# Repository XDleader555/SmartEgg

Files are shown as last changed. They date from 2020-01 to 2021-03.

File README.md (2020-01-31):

# SmartEgg
Data collection firmware for an ESP32 based egg drop.

## Usage
See the [wiki page](https://github.com/XDleader555/SmartEgg/wiki) for help operating the egg.

## Specifications
MCU: [Adafruit HUZZAH32](https://www.adafruit.com/product/3405)

Weight: 76.25 grams

Material: PET-G

Width: 53.10 mm (2.09 in)

Height: 70.53 mm (2.78 in)

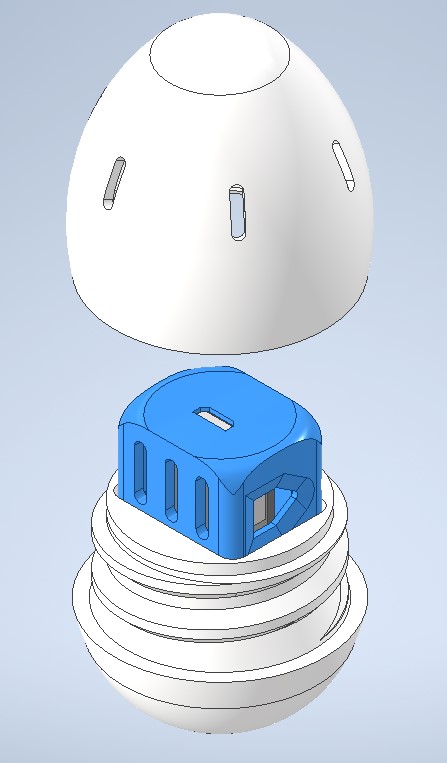
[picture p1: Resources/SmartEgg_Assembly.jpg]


## Prerequisites
This project needs to be compiled using the latest esp-idf which supports the ardino-esp32 core.
You'll also need esptool. win32 mkspiffs is included.

### esptool
Make sure that python is added to your path and run
```
pip install esptool
```

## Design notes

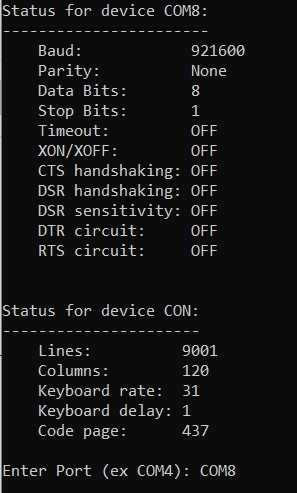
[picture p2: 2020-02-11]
Resources/COM Port.jpg

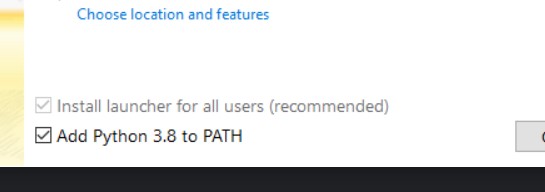
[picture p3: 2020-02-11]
Resources/Python Path.jpg

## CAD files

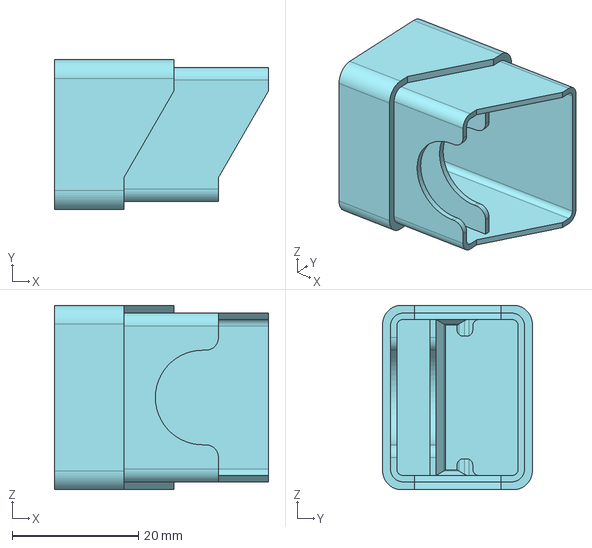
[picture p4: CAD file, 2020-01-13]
CAD/STEP/SmartEgg Housing Main.stp
33.9 x 23.8 x 29.2 mm

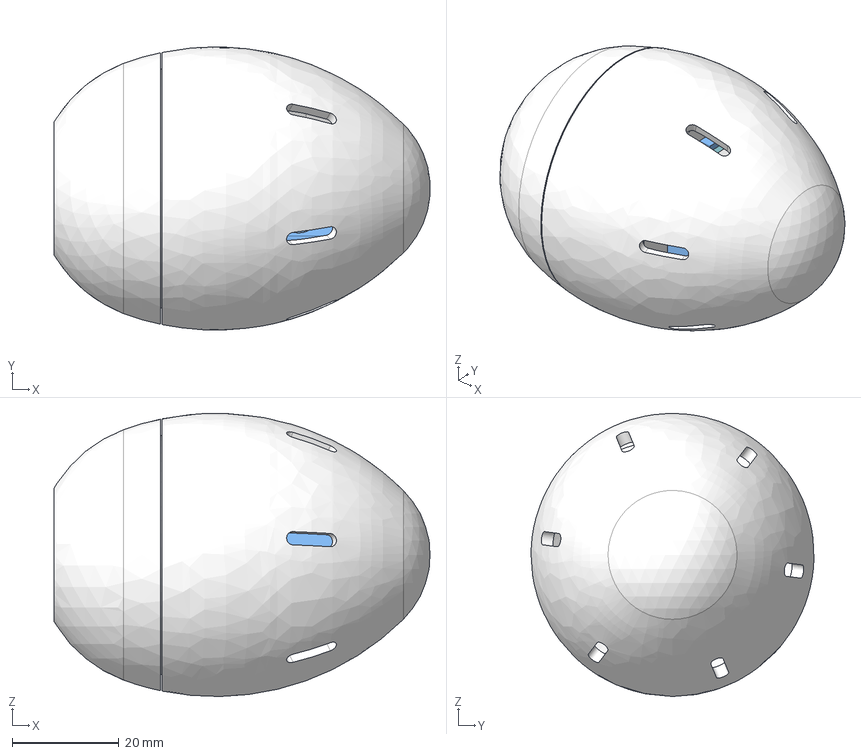
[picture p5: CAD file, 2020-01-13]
CAD/STEP/SmartEgg.stp
70.5 x 53.0 x 53.0 mm
ESP32 Feather
SmartEgg Housing Main
SmartEgg Housing Cap
SmartEgg Shell Top
SmartEgg Shell

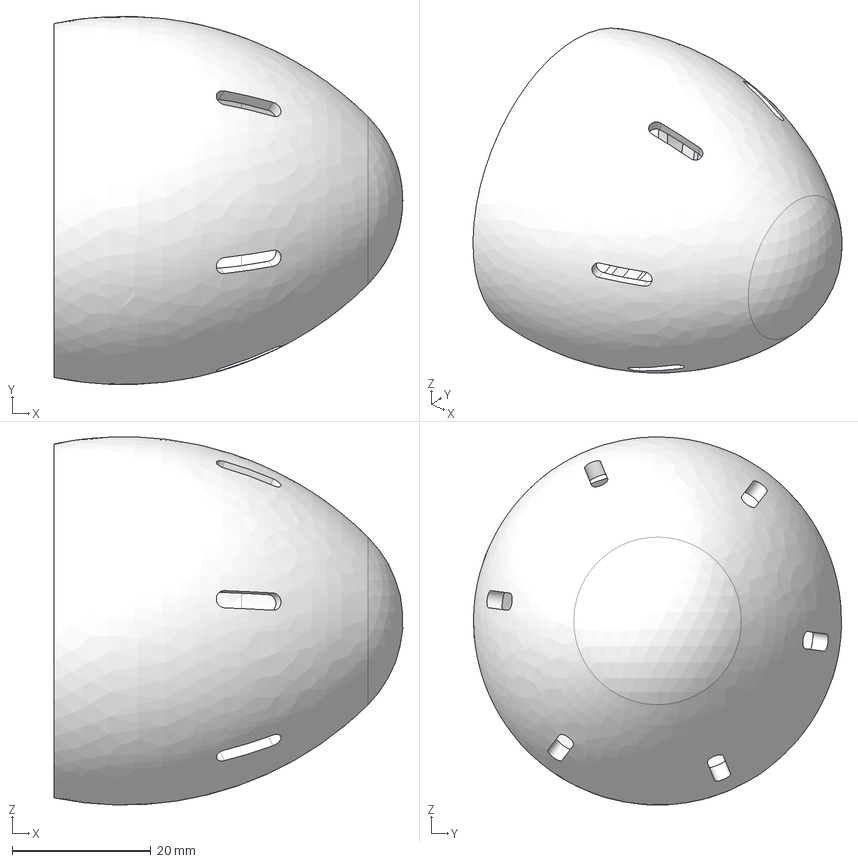
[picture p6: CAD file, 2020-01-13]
CAD/STEP/SmartEgg Shell Top.stp
50.2 x 53.0 x 53.0 mm

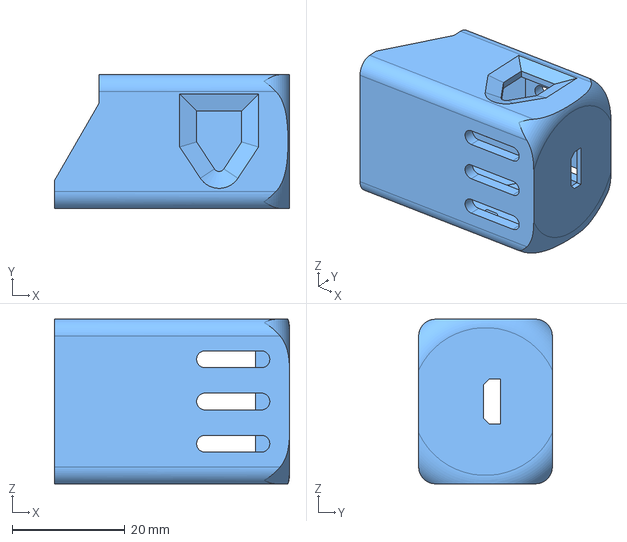
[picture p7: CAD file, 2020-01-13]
CAD/STEP/SmartEgg Housing Cap.stp
41.8 x 23.8 x 29.2 mm

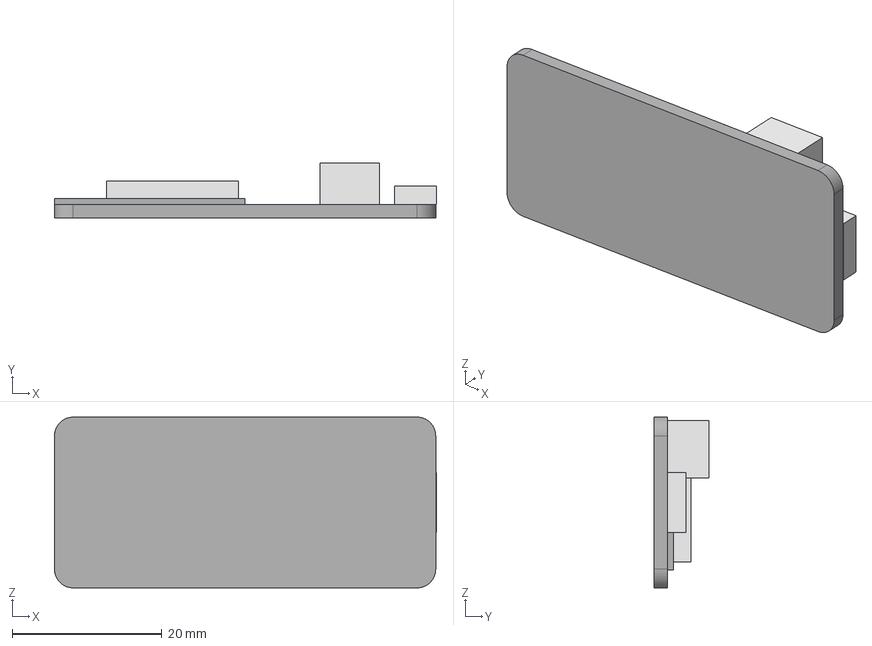
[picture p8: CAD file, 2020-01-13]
CAD/STEP/ESP32 Feather.stp
51.1 x 7.30 x 22.9 mm

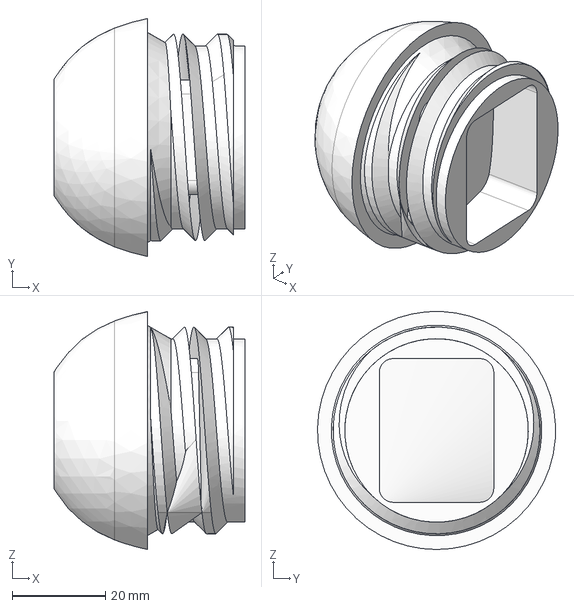
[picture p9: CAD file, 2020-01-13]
CAD/STEP/SmartEgg Shell.stp
40.9 x 50.9 x 50.9 mm

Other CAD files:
CAD/ESP32 Feather.ipt
CAD/OldVersions/ESP32 Feather.0007.ipt
CAD/OldVersions/SmartEgg Housing Cap.0034.ipt
CAD/OldVersions/SmartEgg Housing Main.0028.ipt
CAD/OldVersions/SmartEgg Shell Top.0019.ipt
CAD/OldVersions/SmartEgg Shell.0040.ipt
CAD/OldVersions/SmartEgg.0006.ipt
CAD/STL/SmartEgg Housing Cap.stl
CAD/STL/SmartEgg Housing Main.stl
CAD/STL/SmartEgg Shell Top.stl
CAD/STL/SmartEgg Shell.stl
CAD/SmartEgg Housing Cap.ipt
CAD/SmartEgg Housing Main.ipt
CAD/SmartEgg Shell Top.ipt
CAD/SmartEgg Shell.ipt
CAD/SmartEgg.iam

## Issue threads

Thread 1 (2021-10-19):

Noisy ADC

XDleader555, 2021-10-19:
See errata 3.11. Move ADC pins from 36 and 39. Cut off top of module to prevent wireless fidelity noise.

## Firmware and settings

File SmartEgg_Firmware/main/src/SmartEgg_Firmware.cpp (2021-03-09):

/*
  SmartEgg_Firmware - Data collection firmware for an ESP32 based egg drop
  Copyright (c) 2019 Andrew Miyaguchi. All rights reserved.

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
  You should have received a copy of the GNU General Public License
  along with this program.  If not, see <https://www.gnu.org/licenses/>.
*/


#include "Commands.h"
#include "SmartEgg.h"
#include "ADXL377.h"
#include "SPIFFS.h"
#include "Huzzuh32.h"
#include <driver/adc.h>
#include <stdlib.h>
#include <DNSServer.h>
#include <MiyaSh.h>
#include <Arduino.h>
#include <AsyncTCP.h>
#include <ESPAsyncWebServer.h>

#define RELEASE_VER "2.1.5"
#define DNS_PORT 53
#define LED_PIN 13
#define BTN_PIN 0

DNSServer dnsServer;
AsyncWebServer m_server(80);

void webServerTask(void *pvParameters);
void dnsServerTask(void *pvParameter);
void miyaShTask(void *pvParameters);
void rollingAvgTask(void *pvParameter);

void onBody(AsyncWebServerRequest *request, uint8_t *data, size_t len, size_t index, size_t total);
void setupWebServer();

void setup() {
  /* Initialize serial communication at 115200 baud */
  Serial.begin(115200);
  Serial.println("\nSerial Communications Begin...");

  Huzzah32.begin();

  //Serial.println("Reducing clock speed to 80Mhz");
  //setCpuFrequencyMhz(80);
  
  /* Print current temperature */
  Serial.printf("Current Temperature: %.1f°F\n", temperatureRead());
  
  /* Setup the global object */
  SMARTEGG.begin();
  SMARTEGG.dataRec->m_server = &m_server;
  setupWebServer();

  SMARTEGG.dataRec->setupWifi();
  
  /* Setup DNS Server to redirect user to main page */
  dnsServer.start(DNS_PORT, "*", WiFi.softAPIP());
  
  /* Start CPU0 tasks, higher number means higher priority */
  xTaskCreatePinnedToCore(dnsServerTask, "dnsServerTask", 4096, NULL, 1, NULL, 0);
  xTaskCreatePinnedToCore(rollingAvgTask, "rollingAvgTask", 4096, NULL, 1, NULL, 0);
  xTaskCreatePinnedToCore(miyaShTask, "miyaguchiShell", 4096, NULL, 1, NULL, 0);

  /* Set the LED HIGH */
  pinMode(LED_PIN, OUTPUT);
  digitalWrite(LED_PIN, HIGH);
}

// Shell Task
void miyaShTask(void *pvParameter) {
  MiyaSh sh;
  
  Serial.println("\nBootup Complete. Initializing shell..."); 
  
  sh.registerCmd("record", "SmartEgg", &recordCmd);
  sh.registerCmd("setAPName", "SmartEgg", &setAPNameCmd);
  sh.registerCmd("getAvgStr", "SmartEgg", &getAvgStrCmd);
  sh.registerCmd("calibrate", "SmartEgg", &calibrateCmd);
  sh.registerCmd("routeVRef", "SmartEgg", &routeVRefCmd);
  sh.registerCmd("setVRef", "SmartEgg", &setVRefCmd);
  sh.registerCmd("setVReg", "SmartEgg", &setVRegCmd);
  sh.registerCmd("stopWifi", "SmartEgg", &stopWifiCmd);
  sh.registerCmd("startWifi", "SmartEgg", &startWifiCmd);
  sh.registerCmd("getbattlevel", "SmartEgg", &getBattLevelCmd);
  
  sh.begin();
  
  // Loop Task 
  for(;;) {
    sh.run();
    vTaskDelay(10);
  }
}

void rollingAvgTask(void *pvParameter) {
  /* Loop Task */
  for(;;) {
    SMARTEGG.accel->updateAvg();
    vTaskDelay(100);
  }
}

void dnsServerTask(void *pvParameter) {
  /* Loop Task */
  for(;;) {
    dnsServer.processNextRequest();
    vTaskDelay(100);
  }
}

/* Application CPU (CPU1) */
void loop() {
  SMARTEGG.dataRec->run();
}

void loopTask(void *pvParameters)
{
    setup();
    for(;;) {
        loop();
        if (serialEventRun) serialEventRun();
    }
}

extern "C" void app_main()
{
    initArduino();
    xTaskCreateUniversal(loopTask, "loopTask", 8192, NULL, 2, NULL, 1);
}

void setupWebServer() {
  /* Setup the Filesystem */
  Serial.print("Mounting filesystem... ");
  if(!SPIFFS.begin(true)){
      Serial.println("SPIFFS Mount Failed!");
      Serial.println("Did you remember to upload the SPIFFS partition?");
      return;
  } else {
    Serial.println("Done");
    Serial.printf("%dKB used out of %dKB\n", SPIFFS.usedBytes()/1024, SPIFFS.totalBytes()/1024);
  }

  /* Setup the WebServer */
  m_server.serveStatic("/", SPIFFS, "/html/").setDefaultFile("index.html");
  
  /* Basic Responses */
  m_server.on("/heap", HTTP_GET, [](AsyncWebServerRequest *request){
    request->send(200, "text/plain", String(ESP.getFreeHeap()));
  });

  m_server.on("/functions/recordStart", HTTP_GET, [](AsyncWebServerRequest *request){
    String recName = request->url().substring(String("/functions/recordStart/").length());
    Serial.printf("[WEBSERVER] recordStart - name: \"%s\"\n", recName.c_str());
    
    int resp = SMARTEGG.recordStart(recName);
    request->send(200, "text/plain", String(resp));
  });

  m_server.on("/functions/disableWifi", HTTP_GET, [](AsyncWebServerRequest *request){
    request->send(200);
    SMARTEGG.dataRec->disableWifi();
  });

  m_server.on("/functions/recordStop", HTTP_GET, [](AsyncWebServerRequest *request){
    Serial.println("[WEBSERVER] recordStop");
    int resp = SMARTEGG.recordStop();
    request->send(200, "text/plain", String(resp));
  });

  m_server.on("/functions/recordDeleteAll", HTTP_GET, [](AsyncWebServerRequest *request){
    Serial.println("[WEBSERVER] recordDeleteAll");
    SMARTEGG.dataRec->deleteAllRecordings();
    request->send(200);
  });

  m_server.on("/functions/recordDelete", HTTP_GET, [](AsyncWebServerRequest *request){
    String recName = request->url().substring(String("/functions/recordDelete/").length());
    Serial.printf("[WEBSERVER] recordDelete -   : \"%s\"\n", recName.c_str());
    SMARTEGG.dataRec->deleteRecording(recName);
    request->send(200);
  });

  m_server.on("/functions/recordList", HTTP_GET, [](AsyncWebServerRequest *request){
    Serial.println("[WEBSERVER] recordList");
    request->send(200, "text/plain", SMARTEGG.dataRec->getRecordingsList());
  });

  m_server.on("/functions/recordStatus", HTTP_GET, [](AsyncWebServerRequest *request){
    Serial.println("[WEBSERVER] recordStatus");
    String status;
    if(SMARTEGG.dataRec->isRecording())
      status = "1";
    else
      status = "0";
    request->send(200, "text/plain", status);
  });

  m_server.on("/functions/calibrate", HTTP_GET, [](AsyncWebServerRequest *request){
    Serial.println("[WEBSERVER] calibrate");
    request->send(200, "text/plain", SMARTEGG.accel->calibrate());
  });

  m_server.on("/functions/recordGetMaxTime", HTTP_GET, [](AsyncWebServerRequest *request){
    request->send(200, "text/plain", String(SMARTEGG.dataRec->getRecordTime()));
  });

  m_server.on("/functions/recordSetMaxTime", HTTP_GET, [](AsyncWebServerRequest *request){
    String recTime = request->url().substring(String("/functions/recordGetAxes/").length());
    Serial.printf("Recieved record time: %s\n", recTime.c_str());

    SMARTEGG.dataRec->setRecordTime(recTime.toInt());    
    request->send(200);
  });

  m_server.on("/functions/recordSpaceLeft", HTTP_GET, [](AsyncWebServerRequest *request){
    request->send(200, "text/plain", String(SMARTEGG.dataRec->getSpaceLeft()/1024) + "/" + String(EEPROM_SIZE/1024));
  });

  m_server.on("/functions/getInstant", HTTP_GET, [](AsyncWebServerRequest *request){
    request->send(200, SMARTEGG.dataRec->getAvgStr());
  });

  m_server.on("/functions/recordGetAxes", HTTP_GET, [](AsyncWebServerRequest *request){
    String recName = request->url().substring(String("/functions/recordGetAxes/").length());
    Serial.printf("Recieved read request with name\"%s\"\n", recName.c_str());
    SMARTEGG.dataRec->chunkedReadInit(recName, READ_AXES);

    AsyncWebServerResponse *response = request->beginChunkedResponse("text/csv", [](uint8_t *buffer, size_t maxLen, size_t index) -> size_t {
      return SMARTEGG.dataRec->chunkedRead(buffer, maxLen, index);
    });

    request->send(response);
  });

  m_server.on("/functions/recordGetMagnitudes", HTTP_GET, [](AsyncWebServerRequest *request){
    String recName = request->url().substring(String("/functions/recordGetMagnitudes/").length());
    Serial.printf("[WEBSERVER] recordGetMagnitudes - name: \"%s\"\n", recName.c_str());
    SMARTEGG.dataRec->chunkedReadInit(recName, READ_MAGNITUDES);

    AsyncWebServerResponse *response = request->beginChunkedResponse("text/csv", [](uint8_t *buffer, size_t maxLen, size_t index) -> size_t {
      return SMARTEGG.dataRec->chunkedRead(buffer, maxLen, index);
    });

    request->send(response);
  });

  /*
  m_server.on("/functions/recordGetMaxMagnitude", HTTP_GET, [](AsyncWebServerRequest *request){
    String recName = request->url().substring(String("/functions/recordGetMaxMagnitude/").length());
    Serial.printf("Recieved read request with name\"%s\"\n", recName.c_str());
    request->send(200, SMARTEGG.dataRec->getMaxMag(recName));
  });
  */

  m_server.on("/functions/setAPName", HTTP_GET, [](AsyncWebServerRequest *request){
    String apName = request->url().substring(String("/functions/setAPName/").length());
    Serial.printf("Requested to set APName to \"%s\"\n", apName.c_str());
    SMARTEGG.dataRec->setAPName(apName);
    
    request->send(200);
  });

  m_server.on("/functions/getAPName", HTTP_GET, [](AsyncWebServerRequest *request){
    request->send(200, "text/plain", SMARTEGG.dataRec->getAPName());
  });

  m_server.on("/functions/getVersion", HTTP_GET, [](AsyncWebServerRequest *request){
    request->send(200, "text/plain", RELEASE_VER);
  });

  m_server.on("/functions/getBatteryLevel", HTTP_GET, [](AsyncWebServerRequest *request){
    float batteryLevel = Huzzah32.readBattery();
    char strLevel[100];

    printf("Battery Level: ");
    if(batteryLevel == -1) {
      request->send(200, "text/plain", "Charging");
    } else {
      sprintf(strLevel, "%.2f\n", batteryLevel);
      request->send(200, "text/plain", strLevel); 
    }
  });

  m_server.on("/functions/reboot", HTTP_GET, [](AsyncWebServerRequest *request){
    request->send(200);

    Serial.println("Going for a restart...");
    delay(100);
    esp_restart();
  });

  m_server.on("/generate_204", HTTP_GET, [](AsyncWebServerRequest *request){
    request->send(204);
  });

  m_server.on("/gen_204", HTTP_GET, [](AsyncWebServerRequest *request){
    request->send(204);
  });

  m_server.on("/bootcount", HTTP_GET, [](AsyncWebServerRequest *request){
    request->send(200, "text/plain", String(SMARTEGG.bootcount));
  });

  m_server.on("/connecttest.txt", HTTP_GET, [](AsyncWebServerRequest *request){
    request->send(200, "text/plain", "Microsoft Connect Test");
  });
  
  /* Handle 404 */
  m_server.onNotFound([](AsyncWebServerRequest *request){
    Serial.printf("NotFound: http://%s%s\n", request->host().c_str(), request->url().c_str());
    request->send(404);
  });

  //m_server.begin(); //Moved to startwifi
}

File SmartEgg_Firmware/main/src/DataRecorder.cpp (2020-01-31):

#include "DataRecorder.h"

DataRecorder::DataRecorder(ADXL377* accel) {
  /* Setup local variables */
  m_recFlag = false;
  m_writeMutex = false;
  m_recNumSamples = 0;
  m_accel = accel;
  m_request = REQUEST_EMPTY;
  m_requestStatus = 0;
  m_chunkedIter = 0;
  
  /* load recording data */
  m_pref = new Preferences();
  m_pref->begin("DataRec", false);
  m_recordings = m_pref->getString("RecordingNames", "");
  m_pref->end();
  Serial.printf("Loaded %d Recordings into ram:\n%s\n", getNumRecordings(), m_recordings.c_str());

  /* Setup the sample rate */
  setSampleRate(REC_HZ);

  /* Setup time to log */
  setRecordTime(RECORD_TIME);

  /* Setup the EEPROM */
  Serial.print("Mounting EEPROM...");
  if(!EEPROM.begin(EEPROM_SIZE)) {
    Serial.println("EEPROM Mount Failed! Did you flash the correct partition table?");
    return;
  } else {    
    Serial.printf("Done\n%luKB/%dKB of EEPROM left for data recording\n",
                    getSpaceLeft()/1024, EEPROM_SIZE/1024);
  }

  /* Setup circular write buffer */
  m_writeBuffer = NULL;
  m_freeAddress = 0;
  m_writeAddress = 0;
}

/* Check how much EEPROM is left */
unsigned long DataRecorder::getSpaceLeft() {
  unsigned long freeEEPROMSize = EEPROM_SIZE;
  
  if(getNumRecordings() > 0) {
    String lastRec = "DR_" + getRecordingName(getNumRecordings() - 1);

    m_pref->begin(lastRec.c_str(), false);
    unsigned long lastRecStartAddr = m_pref->getULong("startAddr", 0);
    unsigned long lastRecNumSamples = m_pref->getULong("numSamples", 0);
    m_pref->end();

    freeEEPROMSize -= (lastRecStartAddr + (lastRecNumSamples * 6));
  }

  return freeEEPROMSize ;
}

void DataRecorder::setAPName(String name) {
  if(name.charAt(0) == '"')
    name = name.substring(1);
  if(name.charAt(name.length() - 1) == '"')
    name = name.substring(0, name.length() - 1);
  
  m_pref->begin("SmartEgg", false);
  m_pref->putString("APName", name);
  m_pref->end();

  Serial.printf("Set AP Name to %s. Please reboot for changes to take effect.\n", name.c_str());
}

String DataRecorder::getAPName() {
  String APName;
  m_pref->begin("SmartEgg", false);
  APName = m_pref->getString("APName", "Nameless SmartEgg");
  m_pref->end();

  return APName;
}

void DataRecorder::setupWifi() {
  /* Make sure everything is disabled */
  WiFi.disconnect();
  WiFi.mode(WIFI_OFF);

  /* Start the WiFi Access Point */
  WiFi.mode(WIFI_AP);
  WiFi.setSleep(false);
  WiFi.softAPsetHostname(getAPName().c_str());
  //WiFi.setTxPower(WIFI_POWER_7dBm);
  WiFi.softAP(getAPName().c_str());
  
  Serial.print("Wireless AP Started: ");
  Serial.println(getAPName().c_str());
  Serial.print("Local IP address: ");
  Serial.println(WiFi.softAPIP());
  m_server->begin();
}

void DataRecorder::disableWifi() {
  m_server->end();
  if(esp_wifi_stop() != ESP_OK) {
    Serial.println("Error disabling wifi");
  } else {
    Serial.println("Disconnected AP");
  }
}

int DataRecorder::getNumRecordings() {
  int numRec = 0;
  for(int i = 0; i < m_recordings.length(); i ++)
    if(m_recordings[i] == '\n')
      numRec++;

  return numRec;
}

String DataRecorder::getRecordingsList() {
  return m_recordings;
}

void DataRecorder::deleteAllRecordings() {
  for(int i = 0; i < getNumRecordings(); i++) {
    m_pref->begin(("DR_" + getRecordingName(i)).c_str(), false);
    m_pref->clear();
    m_pref->end();
  }

  m_recordings = "";
  m_pref->begin("DataRec", false);
  m_pref->putString("RecordingNames", m_recordings);
  m_pref->end();
}

void DataRecorder::deleteRecording(String recordingName) {
  if(m_recordings.indexOf(recordingName) == -1) {
    Serial.println("Could not delete recording: Not found");
    return;
  }

  /* Delete recording from preferences */
  m_pref->begin(("DR_" + recordingName).c_str(), false);
  m_pref->clear();
  m_pref->end();

  /* Remove recording from list */
  String temp = "";
  for(int i = 0; i < getNumRecordings(); i++){
    String tempRecName = getRecordingName(i);
    if(tempRecName != recordingName)
      temp += tempRecName + "\n";
  }
  m_recordings = temp;
  
  m_pref->begin("DataRec", false);
  m_pref->putString("RecordingNames", m_recordings);
  m_pref->end();
  
  defragment();

  Serial.printf("Deleted \"%s\"\n", recordingName.c_str());
  Serial.print(m_recordings.c_str());
  Serial.printf("%luKB/%dKB of EEPROM left for data recording\n",
              getSpaceLeft()/1024,
              EEPROM_SIZE/1024);
}

/*
 * Make the recordings continuous instead of dynamically allocated
 * in EEPROM memory because I'm feeling lazy
 */
void DataRecorder::defragment() {
  for(int i = 0; i < getNumRecordings(); i++) {
    m_pref->begin(("DR_" + getRecordingName(i)).c_str(), false);
    unsigned long currStartAddr = m_pref->getULong("startAddr", 0);
    unsigned long currSize = EEPROM.align(m_pref->getULong("numSamples", 0) * 6);
    m_pref->end();
    
    unsigned long calcStartAddr = calcNextStartAddress(i - 1);

    if(currStartAddr != calcStartAddr) {
      /* Copy to the defrag area, then to the new start Addr */
      EEPROM.copy(currStartAddr, calcStartAddr, currSize);
      
      m_pref->begin(("DR_" + getRecordingName(i)).c_str(), false);
      m_pref->putULong("startAddr", calcStartAddr);
      m_pref->end();
    }
    
  }
}

String DataRecorder::getRecordingName(int index) {
  String recName = "" + m_recordings;

  /* Remove leading names */
  for(int i = 0; i < index; i ++) {
    if(recName.indexOf('\n') == -1)
      return ""; /* Return empty if index is out of range */
      
    recName = recName.substring(recName.indexOf('\n') + 1);
  }

  /* Remove trailing names */
  if(recName.indexOf('\n') != -1) {
    recName = recName.substring(0, recName.indexOf('\n'));
  }

  //Serial.printf("Found \"%s\" at index %d\n", recName.c_str(), index);
  return recName;
}

bool DataRecorder::recordingExists(String recName) {
  for(int i = 0; i < getNumRecordings(); i ++)
    if(recName == getRecordingName(i))
      return true;
      
  return false;
}

/* Send a start record request tot he main core */
int DataRecorder::recordStart(String recordingName) {
  if(recordingExists(recordingName)) {
    Serial.println("Name for recording already exists!");
    return -1;
  }

  m_currRecording = recordingName;
  
  return request(REQUEST_START);
}
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

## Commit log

2019-07-05 Upload v1.0
    [SmartEgg_Partition.csv]
2019-07-05 Update to arduino-esp32 v1.0.2 and esp-idf v3.2 - Rename WebServer to SmartEggWebServer to avoid compilation conflicts - Change ADXL377 pinout to power off GPIO and reduce soldering complexity - Run 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
    [ADXL377.cpp, DataRecorder.cpp, SmartEgg.cpp]
2019-07-06 Upload custom boards.txt to show partiton layout
2019-07-11 Major library rework (In Progress)
    - Use external MiyaFunctions library
    - Use external MiyaSh library
    - Prepare to move commands from Terminal.h to Commands.h
    - Replace Terminal task with MiyaSh task
    [SmartEgg_Firmware.ino]
2019-07-11 Tweak firmware for better wifi performance
    - Disable brownout Tx power reduction
    - Use external crystal for RTC
    - Force primary oscillator as 26Mhz
    - Prefer wifi when bluetooth is enabled
    - Increase static Rx buffers from 8 to 16
    - Increase dynamic Rx buffers from 16 to 64
    - Increase dynamic Tx buffer from 32 to 64
    - Disable AMPDU (Since we should only have one client)
    - Pin wifi task to core 1
    - Pin TCPIP task to core 1
    - Enable LWIP optimizations
    - Double the TCP Window
    - Increase TCPIP Task size
    - Disable experimental PPP support (not needed)
2019-07-17 Add button press counting
2019-11-26 Initial Module Design
    [ESP32 Feather.0001.ipt, ESP32 Feather.ipt, SmartEgg Housing Main.0001.ipt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]
2019-11-26 Completed CAD Model
    [ESP32 Feather.0001.ipt, ESP32 Feather.0005.ipt, ESP32 Feather.ipt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]
2019-11-26 Add cooling vents and increase thread size
    [SmartEgg Housing Cap.0025.ipt, SmartEgg Housing Cap.0028.ipt, SmartEgg Housing Cap.ipt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]
2019-11-26 Export CAD
    [SmartEgg Housing Cap.stl, SmartEgg Housing Main.stl, SmartEgg Shell Top.stl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]
2019-11-26 Optimize Module Wall Thickness
    [SmartEgg Housing Cap.0028.ipt, SmartEgg Housing Cap.0030.ipt, SmartEgg Housing Cap.ipt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]
2019-11-27 Add emboss and loosen constraints
    [ESP32 Feather.0005.ipt, ESP32 Feather.0007.ipt, ESP32 Feather.ipt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]
2019-11-27 Increase tolerance and move emboss
    [SmartEgg Shell Top.0014.ipt, SmartEgg Shell Top.0016.ipt, SmartEgg Shell Top.ipt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]
2019-12-18 Increase yolk tolerance and beef up thread base
    [SmartEgg Shell Top.0016.ipt, SmartEgg Shell Top.0019.ipt, SmartEgg Shell Top.ipt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]
2020-01-13 Add initial assembly instructions
2020-01-13 Add assembly instructions
2020-01-13 Export as step
    [ESP32 Feather.stp, SmartEgg Housing Cap.stp, SmartEgg Housing Main.stp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]
2020-01-13 Remove OldVersions folder
    [SmartEgg.0024.iam]
2020-01-13 Constrain the assembly before export
    [SmartEgg.iam, SmartEgg.stp]
2020-01-13 Upload screenshot of assembly
2020-01-13 disable manual calibration if factory calibration exists
2020-01-17 Ignore invalid pin assignment
2020-01-17 Initial refactor for esp-idf
    [SmartEgg_Partition.csv]
2020-01-17 Move files to the correct folders and fix compiler errors
    [ADXL377.cpp, DataRecorder.cpp, SmartEgg.cpp]
2020-01-20 Add initial tx power changes
2020-01-24 Improve user interface for adc workaround
    [SmartEgg_Firmware.cpp]
2020-01-24 Add LED task and delay by 1 second to filter data
2020-01-27 Add battery level and apname to website
2020-01-27 Allow async TCP watchdog timer
2020-01-28 Attempt to fix data transfer issues
    [DataRecorder.cpp, SmartEgg_Firmware.cpp]
2020-01-29 Disable battery and connection status for now
2020-01-29 Update arduino component
2020-01-30 Update arduino library to esp-idf 4.0
2020-01-31 Keep track of boot count to allow website to detect software resets
    [DataRecorder.cpp, SmartEgg.cpp, SmartEgg_Firmware.cpp]
2020-01-31 Adjust battery reading
2020-02-06 2.1.5 Use iperf sdk config to fix wifi issues
    Bump to 2.1.5 and release
    [SmartEgg_Firmware.cpp]

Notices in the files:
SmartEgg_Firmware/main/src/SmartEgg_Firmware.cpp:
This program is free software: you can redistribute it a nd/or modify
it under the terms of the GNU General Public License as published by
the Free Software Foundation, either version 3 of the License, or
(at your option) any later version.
